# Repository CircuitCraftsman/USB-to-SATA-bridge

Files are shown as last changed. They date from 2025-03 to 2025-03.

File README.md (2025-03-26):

# Open-Source SATA to USB 3.0 bridge 🔧

 The main chip is TUSB9261 from Texas Instruments. It is compatible with SATA 1.5-Gbps or SATA 3.0-Gbps devices. The TUSB9261 comes with loaded firmware. Therefore, you don't have to write firmware.
 
📍 The PCB was designed in 4 layers: Signal-Gnd-Pwr-Signal.

📍 SATA signals are routed as differential pair 100Ω (single-ended 50Ω) and length matched within 2.5 mil tolerance.

📍 USB 3.0 super speed signals are also differential pair 90Ω (single-ended 50Ω) and length matched.

 📍 JLC04161H-3313 controlled impedance PCB stackup.

📍The small fan was used to cool down the main chip. It is optional

# Contents
- [System Block Diagram](#Sytem-Block-Diagram)
- [3D Views](#3D-Views)
- [MCU](#MCU)
- [Power](#Power)
- [Layout](#Layout)
- [DC PDN Simulation](#DC-PDN-Simulation)
- [Assembly Drawing](#Assembly-Drawing)

# System Block Diagram

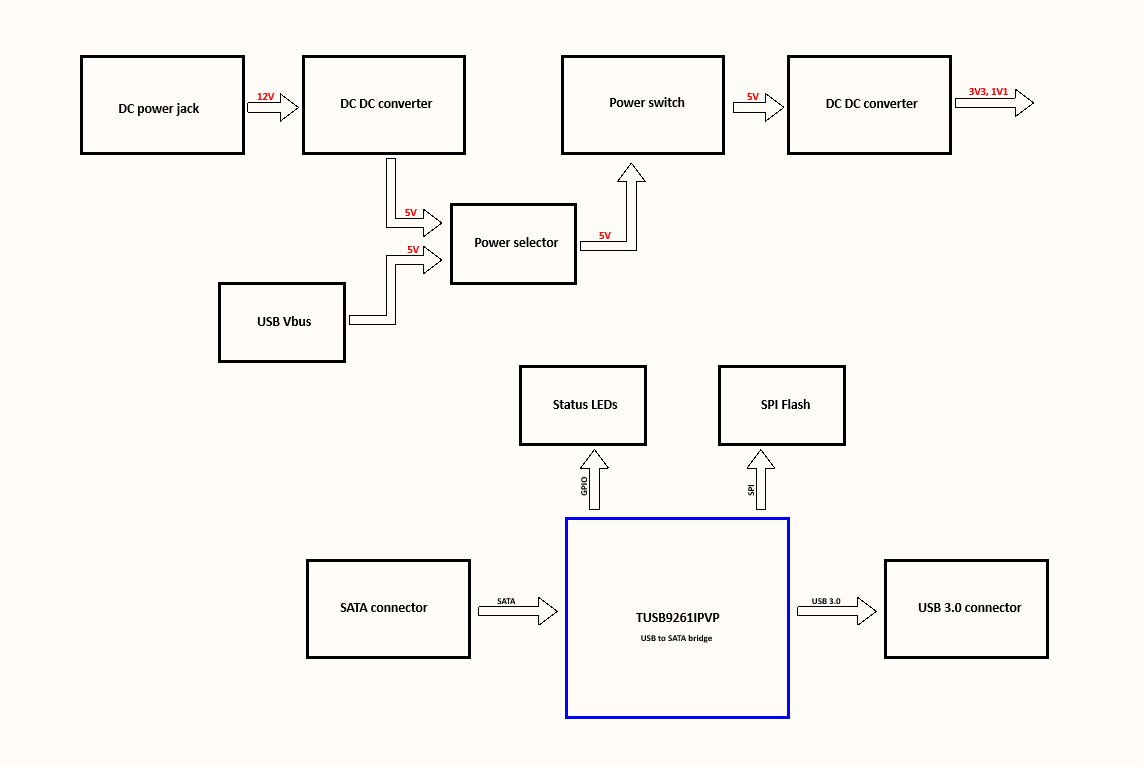
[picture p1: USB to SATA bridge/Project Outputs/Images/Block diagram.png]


# 3D Views

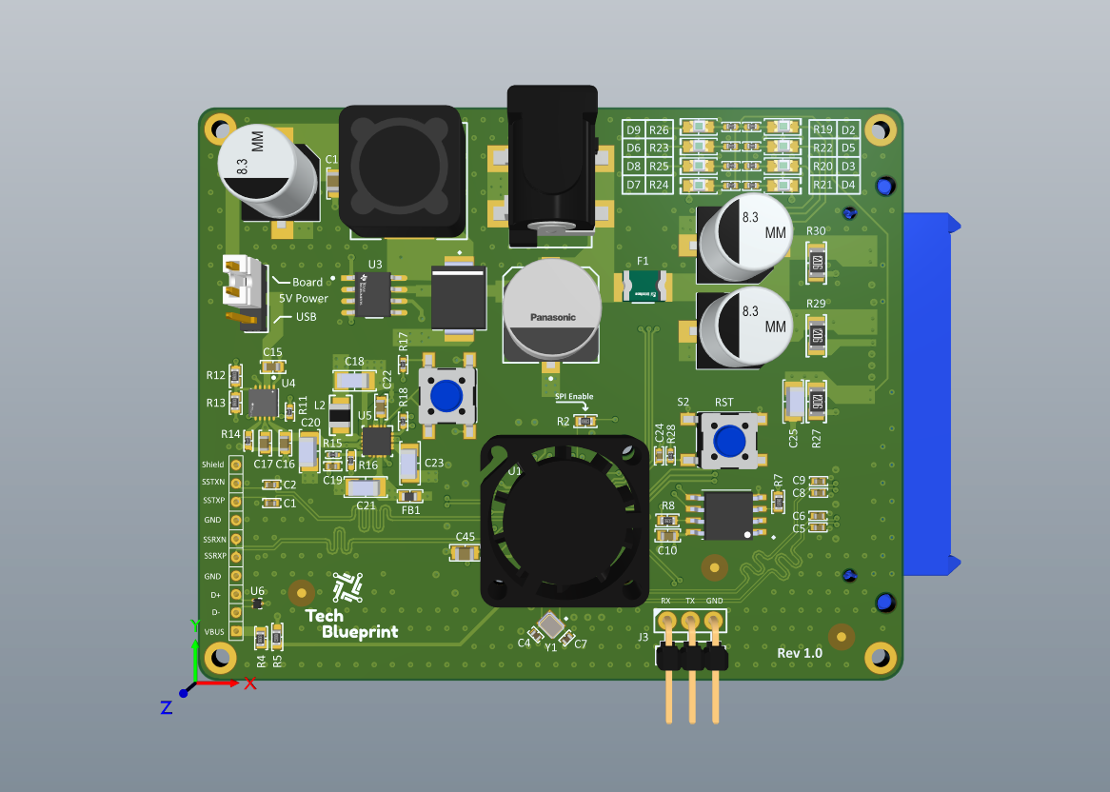
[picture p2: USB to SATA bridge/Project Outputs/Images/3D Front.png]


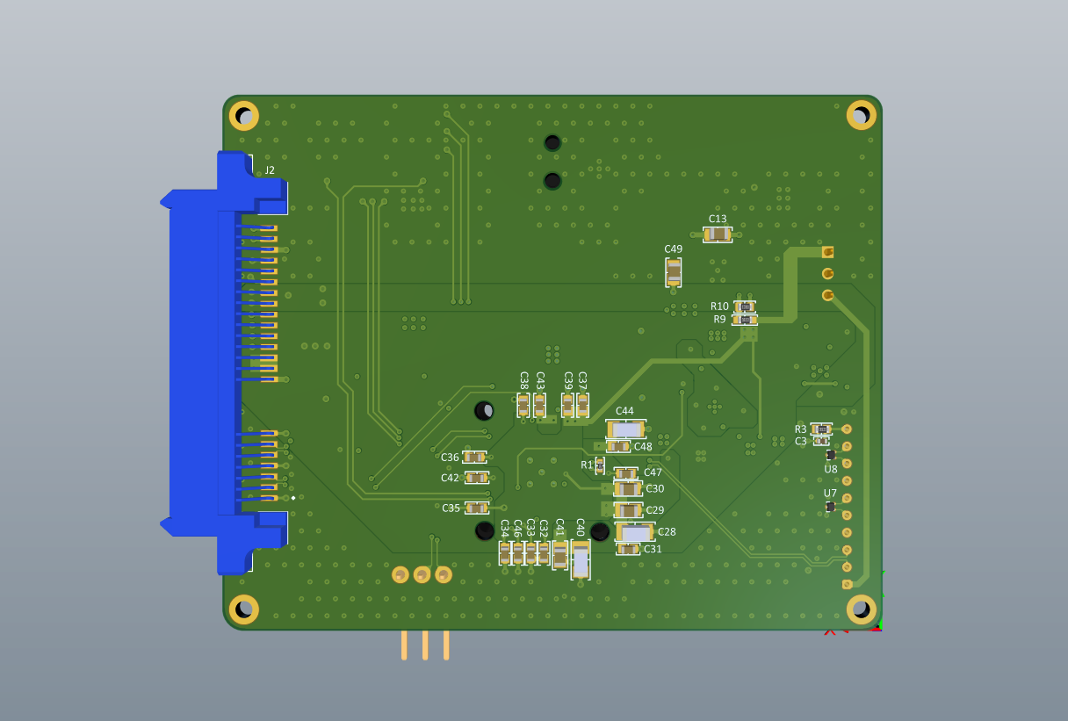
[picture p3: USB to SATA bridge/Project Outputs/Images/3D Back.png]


# MCU

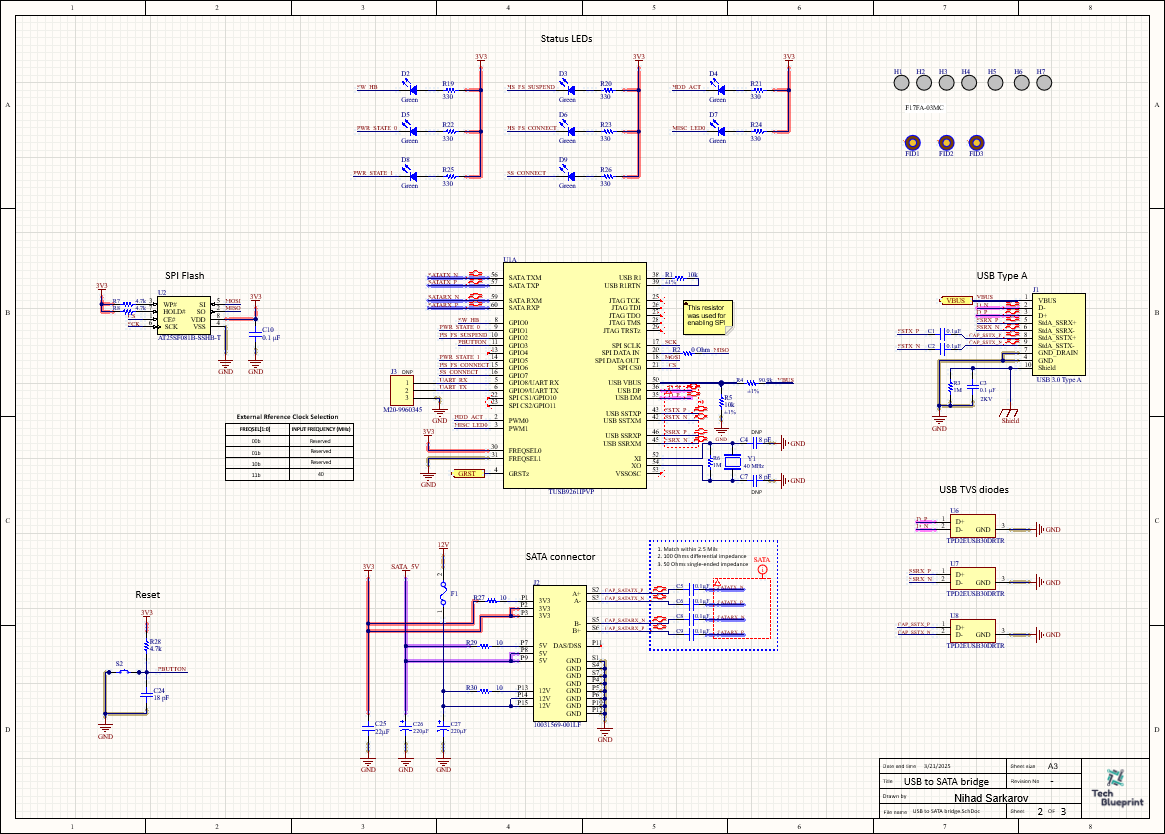
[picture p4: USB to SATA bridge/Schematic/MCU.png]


# Power

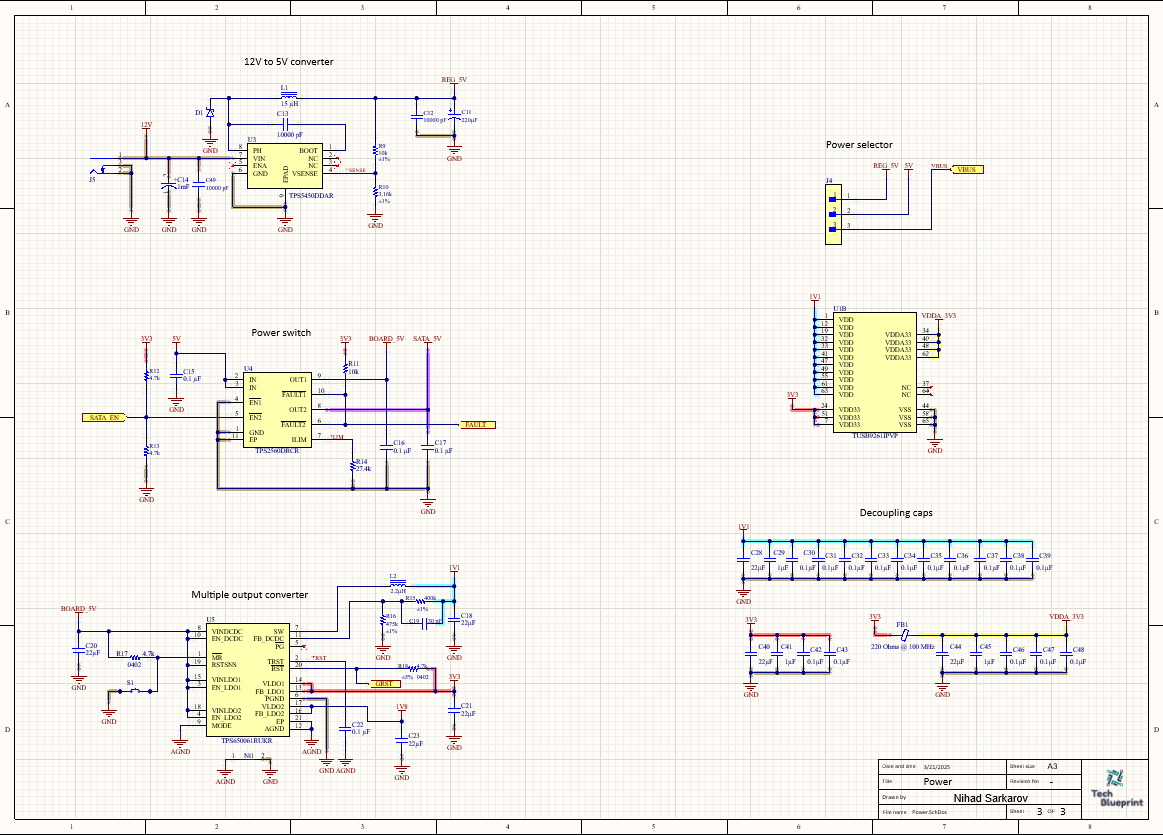
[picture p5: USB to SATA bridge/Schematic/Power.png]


# Layout

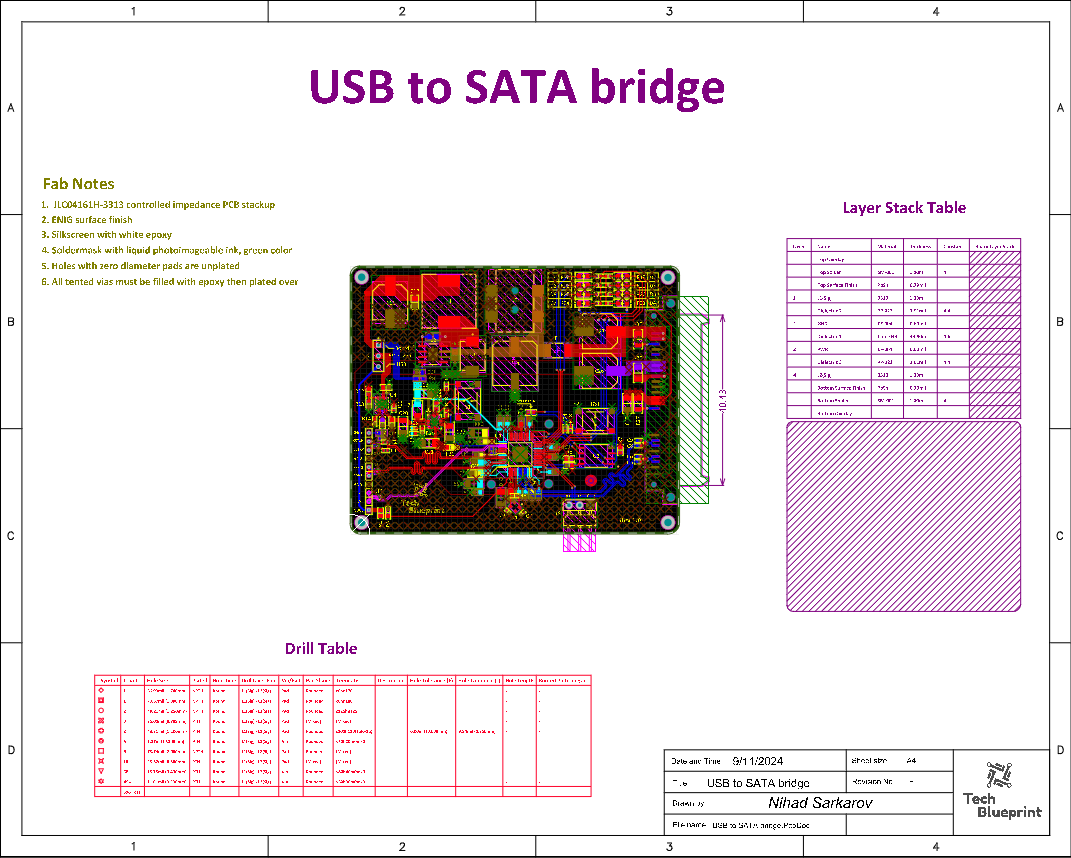
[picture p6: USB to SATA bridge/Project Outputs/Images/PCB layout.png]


# DC PDN Simulation

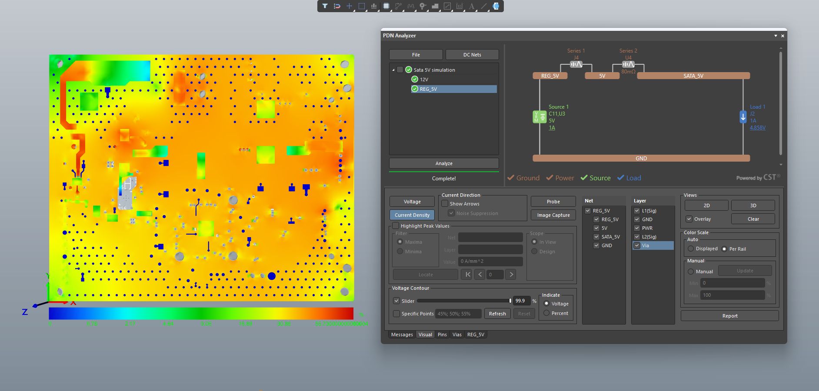
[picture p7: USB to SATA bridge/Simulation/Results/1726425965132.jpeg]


# Assembly Drawing

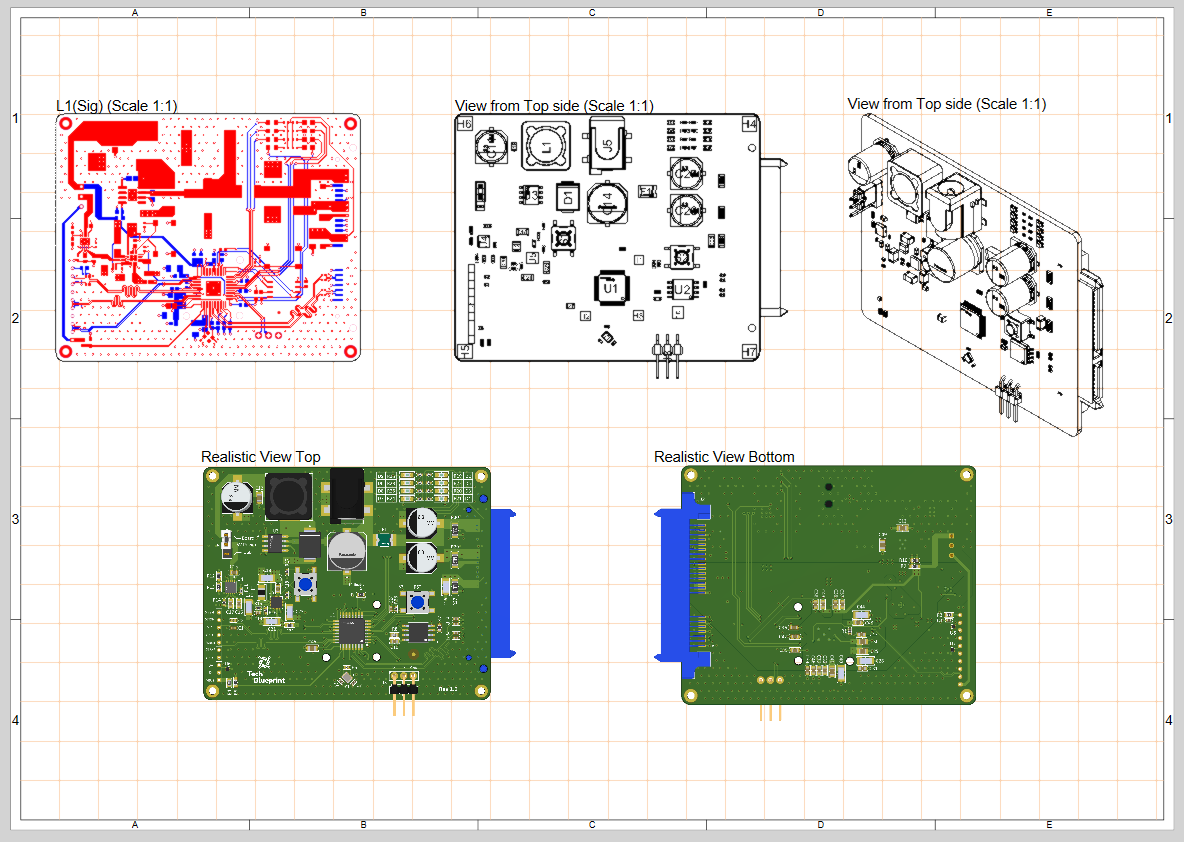
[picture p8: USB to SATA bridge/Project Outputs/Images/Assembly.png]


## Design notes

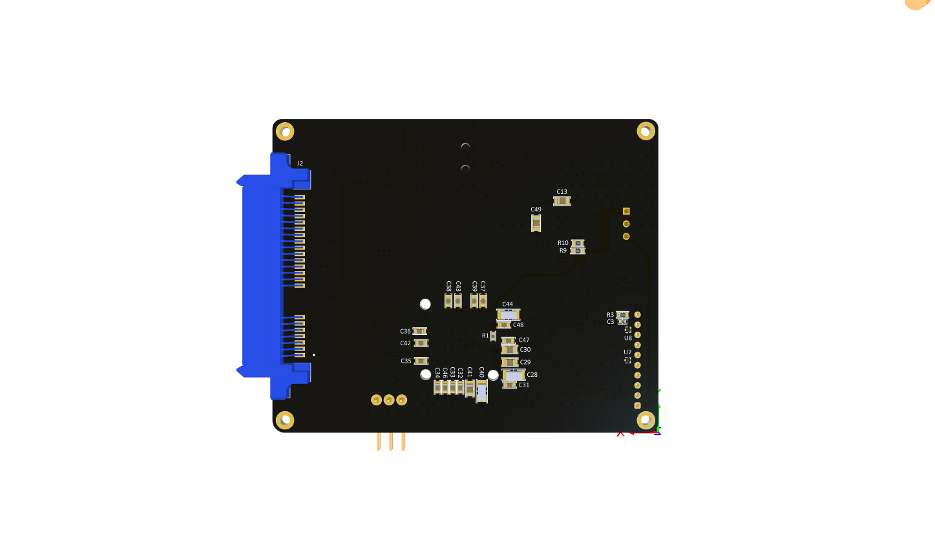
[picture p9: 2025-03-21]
USB to SATA bridge/Project Outputs/Images/PCB back view.png

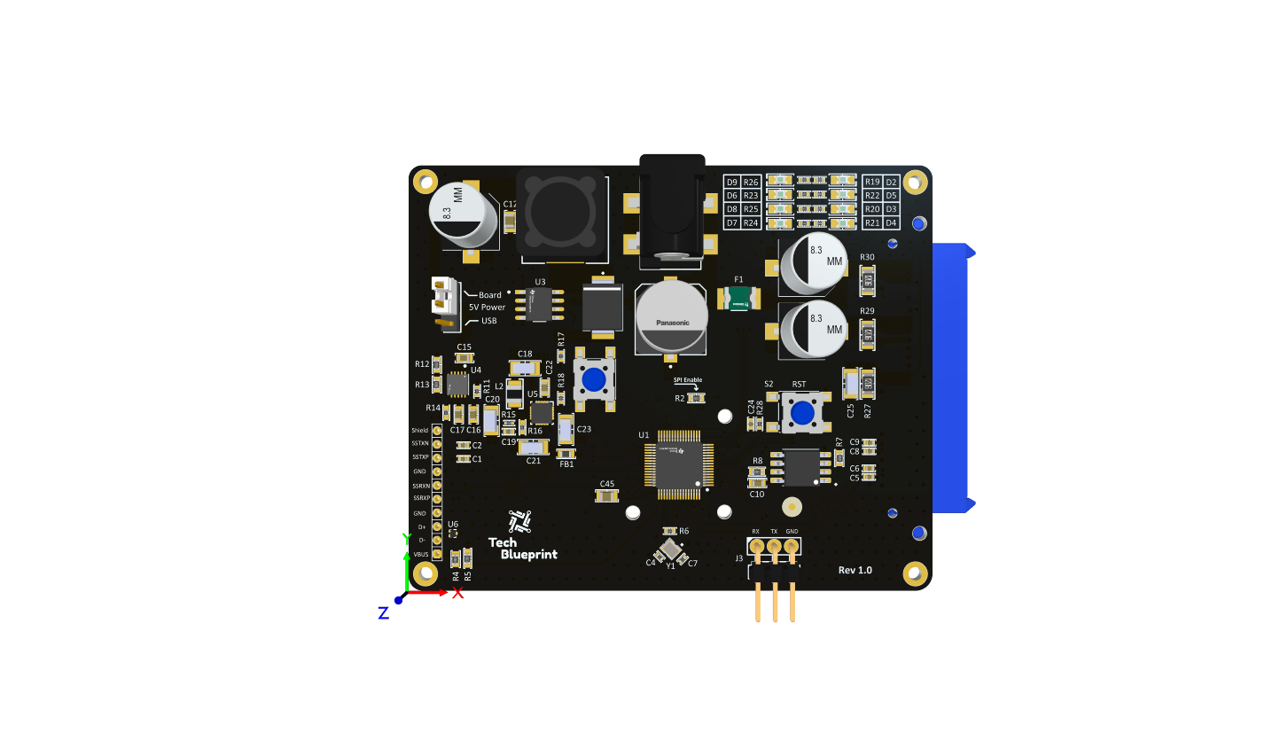
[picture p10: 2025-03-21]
USB to SATA bridge/Project Outputs/Images/PCB front view.png

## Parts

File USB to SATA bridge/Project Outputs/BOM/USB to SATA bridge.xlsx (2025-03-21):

Comment | Description | Designator | Footprint | LibRef | Quantity
0.1µF | CAP CER 0.1UF 16V X7R 0402 | C1, C2, C5, C6, C8, C9 | CAP 0402_1005 | 0402YC104JAT4A | 6
0.1 µF | CAP CER 0.1UF 100V X5R 0402 | C3 | MURATA GRM155 0402_1005 | GRM155R62A104ME14D | 1
8 pF | CAP CER 8PF 50V C0G/NP0 0402 | C4, C7 | MURATA GCM155 0402_1005 | GCM1555C1H8R0DA16D | 2
0.1 µF | CAP CER 0.1UF 50V X7R 0603 | C10, C15, C16, C17, C22 | CAP 0603_1608 | CL10B104KB85PND | 5
220µF | CAP ALUM 220UF 20% 25V SMD | C11, C26, C27 | CAP ALSMD 8.3MM H10.5MM | UUR1E221MNL6GS | 3
10000 pF | CAP CER 0805 10NF 100V X7R | C12, C13, C49 | CAP 0805_2012 | C0805X103K1RAC3316 | 3
EEEFT1C102AP | CAP ALUM 1000UF 20% 16V SMD | C14 | FP-FTG-MFG | CMP-05427-000086-1 | 1
22µF | CAP CER 22UF 16V X5R 1206 | C18, C20, C21, C23, C25, C28, C40, C44 | CAP 1206_3216 - 1.8MM | 1206YD226KAT2A | 8
30 pF | CAP CER 30PF 50V NP0 0402 | C19 | CAP 0402_1005 | C0402C300K5GAC7867 | 1
18 pF | CAP CER 18PF 50V C0G 0402 | C24 | CAP 0402_1005 | CGA2B2C0G1H180J050BA | 1
1µF | CAP CER 1UF 10V X7R 0805 | C29, C41, C45 | CAP 0805_2012 | MM05ZC105KCZ2A | 3
0.1µF | CAP CER 0.1UF 25V X7R 0805 | C30 | CAP 0805_2012 | 08053C104KAT4A | 1
0.1µF | CAP CER 0.1UF 25V X7R 0603 | C31, C32, C33, C34, C35, C36, C37, C38, C39, C42, C43, C46, C47, C48 | CAP 0603_1608 | 06033C104K4T4A | 14
MBRS540T3G |  | D1 | DIOM7959X261N | MBRS540T3G | 1
Green | 0805 LED RED 570NM DOMINANT, 565 | D2, D3, D4, D5, D6, D7, D8, D9 | LED 0805_2012 GREEN | QBLP631-YG1-2943 | 8
MINISMDC150F/24-2 | PTC RESET FUSE 24V 1.5A 1812 | F1 | FP-MINISMDC150F-MFG | CMP-08606-000055-1 | 1
220 Ohms @ 100 MHz | POWER LINE HIGH IMPEDANCE FERRIT | FB1 | FER 0603_1608 | Z0603C221BPWZT | 1
Hole |  | H1, H2, H3 | HOLE | Hole | 3
Mounting hole |  | H4, H5, H6, H7 | Mounting hole | Mounting hole | 4
USB 3.0 Type A | USB 3.0 Type A male connector | J1 | USB 3.0 TYPE A | USB 3.0 Type A | 1
10031569-001LF |  | J2 | AMPHENOL_10031569-001LF | 10031569-001LF | 1
M20-9960345 | CONN HEADER R/A 3POS 2.54MM | J3 | HARWIN M20-9960345 | M20-9960345 | 1
87224-3 | CONN HEADER VERT 3POS 2.54MM | J4 | FP-87224-3-MFG | CMP-2000-05697-2 | 1
PJ-002AH-SMT-TR | CONN PWR JACK 2X5.5MM SOLDER | J5 | CUI PJ-002AH-SMT-TR | PJ-002AH-SMT-TR | 1
15 µH | FIXED IND 15UH 5.2A 28.5MOHM SMD | L1 | BOURNS SRR1280 | SRR1280-150M | 1
2.2µH | FIXED IND 2.2UH 700MA 150 MOHM | L2 | IND 1008_2520 | CKP2520V2R2M-T | 1
10k | RES 10K OHM 1% 1/5W 0402, RES SMD 10K OHM 5% 1/16W 0402 | R1, R11 | YAGEO RES 0402_1005 | SR0402FR-7T10KL, AC0402JR-0710KL | 2
0 Ohm | RCS0603 0R0 ET6 E3 | R2 | RES 0603_1608 | RCS06030000Z0EC | 1
1M | RES 1M OHM 5% 1/10W 0603 | R3 | RES 0603_1608 | RMCF0603JT1M00 | 1
90.9k | RES SMD 90.9K OHM 1% 1/8W 0603 | R4 | RES 0603_1608 | MCT06030C9092FP500 | 1
10k | RES SMD 10K OHM 1% 1/10W 0603 | R5, R9 | YAGEO RES 0603_1608 | RT0603FRE0710KL | 2
1M | RES SMD 1M OHM 5% 1/16W 0402 | R6 | YAGEO RES 0402_1005 | AC0402JR-071ML | 1
4.7k | RES 4.7K OHM 5% 1/10W 0603 | R7, R8, R12, R13 | RES 0603_1608 | RMCF0603JT4K70 | 4
3.16k | RES SMD 3.16K OHM 1% 1/10W 0603 | R10 | RES 0603_1608 | CR0603-FX-3161ELF | 1
27.4k | RES SMD 27.4K OHM 1% 1/10W 0402 | R14 | RES 0402_1005 | ERJ-2RKF2742X | 1
400k | RES 400K OHM 1% 1/10W 0402 | R15 | KOA RES RK73 RN73 0402_1005 | RK73H1ETTP4123F | 1
475k | RES 475K OHM 1% 1/16W 0402 | R16 | RES 0402_1005 | RMCF0402FT475K | 1
4.7k | RES SMD 4.7K OHM 5% 1/16W 0402 | R17, R18, R28 | YAGEO RES 0402_1005 | AC0402JR-074K7L | 3
330 | RES SMD 330 OHM 5% 1/16W 0402 | R19, R20, R21, R22, R23, R24, R25, R26 | YAGEO RES 0402_1005 | AC0402JR-07330RL | 8
10 | RCC1206 200 10R 5% ET1 E3 | R27, R29, R30 | RES 1206_3216 | RCC120610R0JNEA | 3
PTS645SM43SMTR92 LFS | SWITCH TACTILE SPST-NO 0.05A 12V | S1, S2 | C&K PTS645 | PTS645SM43SMTR92 LFS | 2
TUSB9261IPVP | HDD, CD, DVD Drive Interface 64-HTQFP (7x7) | U1 | FP-PVP0064A-IPC_A | TUSB9261IPVP | 1
AT25SF081B-SSHB-T | FLASH - NOR Memory IC 8Mbit SPI - Quad I/O 108 MHz 8-SOIC | U2 | SOIC127P790X216-8N | SST25VF016B-75-4I-S2AF-T | 1
TPS5450DDAR | IC REG BUCK ADJUSTABLE 5A 8SOPWR | U3 | FP-DDA0008J-IPC_A | CMP-04918-000100-1 | 1
TPS2560DRCR | IC PWR SWITCH N-CHAN 1:2 10VSON | U4 | FP-DRC0010J-IPC_A | CMP-0337-00200-3 | 1
TPS650061RUKR | 1 A, 2.25 MHz Step-Down Converter with Dual LDOs & SVS, 2.3 to 6 V, -40 to 85 degC, 20-pin WQFN (RUK), Green (RoHS & no Sb/Br) | U5 | RUK0020B | CMP-1518-00013-2 | 1
TPD2EUSB30DRTR | ESD Solution for Super-Speed (6 Gbps) USB 3.0 Interface, 2 Channels, -40 to +85 degC, 3-pin SOT (DRT), Green (Rohs & No Sb/Br) | U6, U7, U8 | DRT0003A | CMP-0326-00046-3 | 3
SXT22412AA07-40.000M | 40 MHz ±50ppm Crystal 12pF 50 Ohms 4-SMD, No Lead | Y1 | XTAL_SXT22412AA16-40.000MT | SXT22412AA07-40.000M | 1

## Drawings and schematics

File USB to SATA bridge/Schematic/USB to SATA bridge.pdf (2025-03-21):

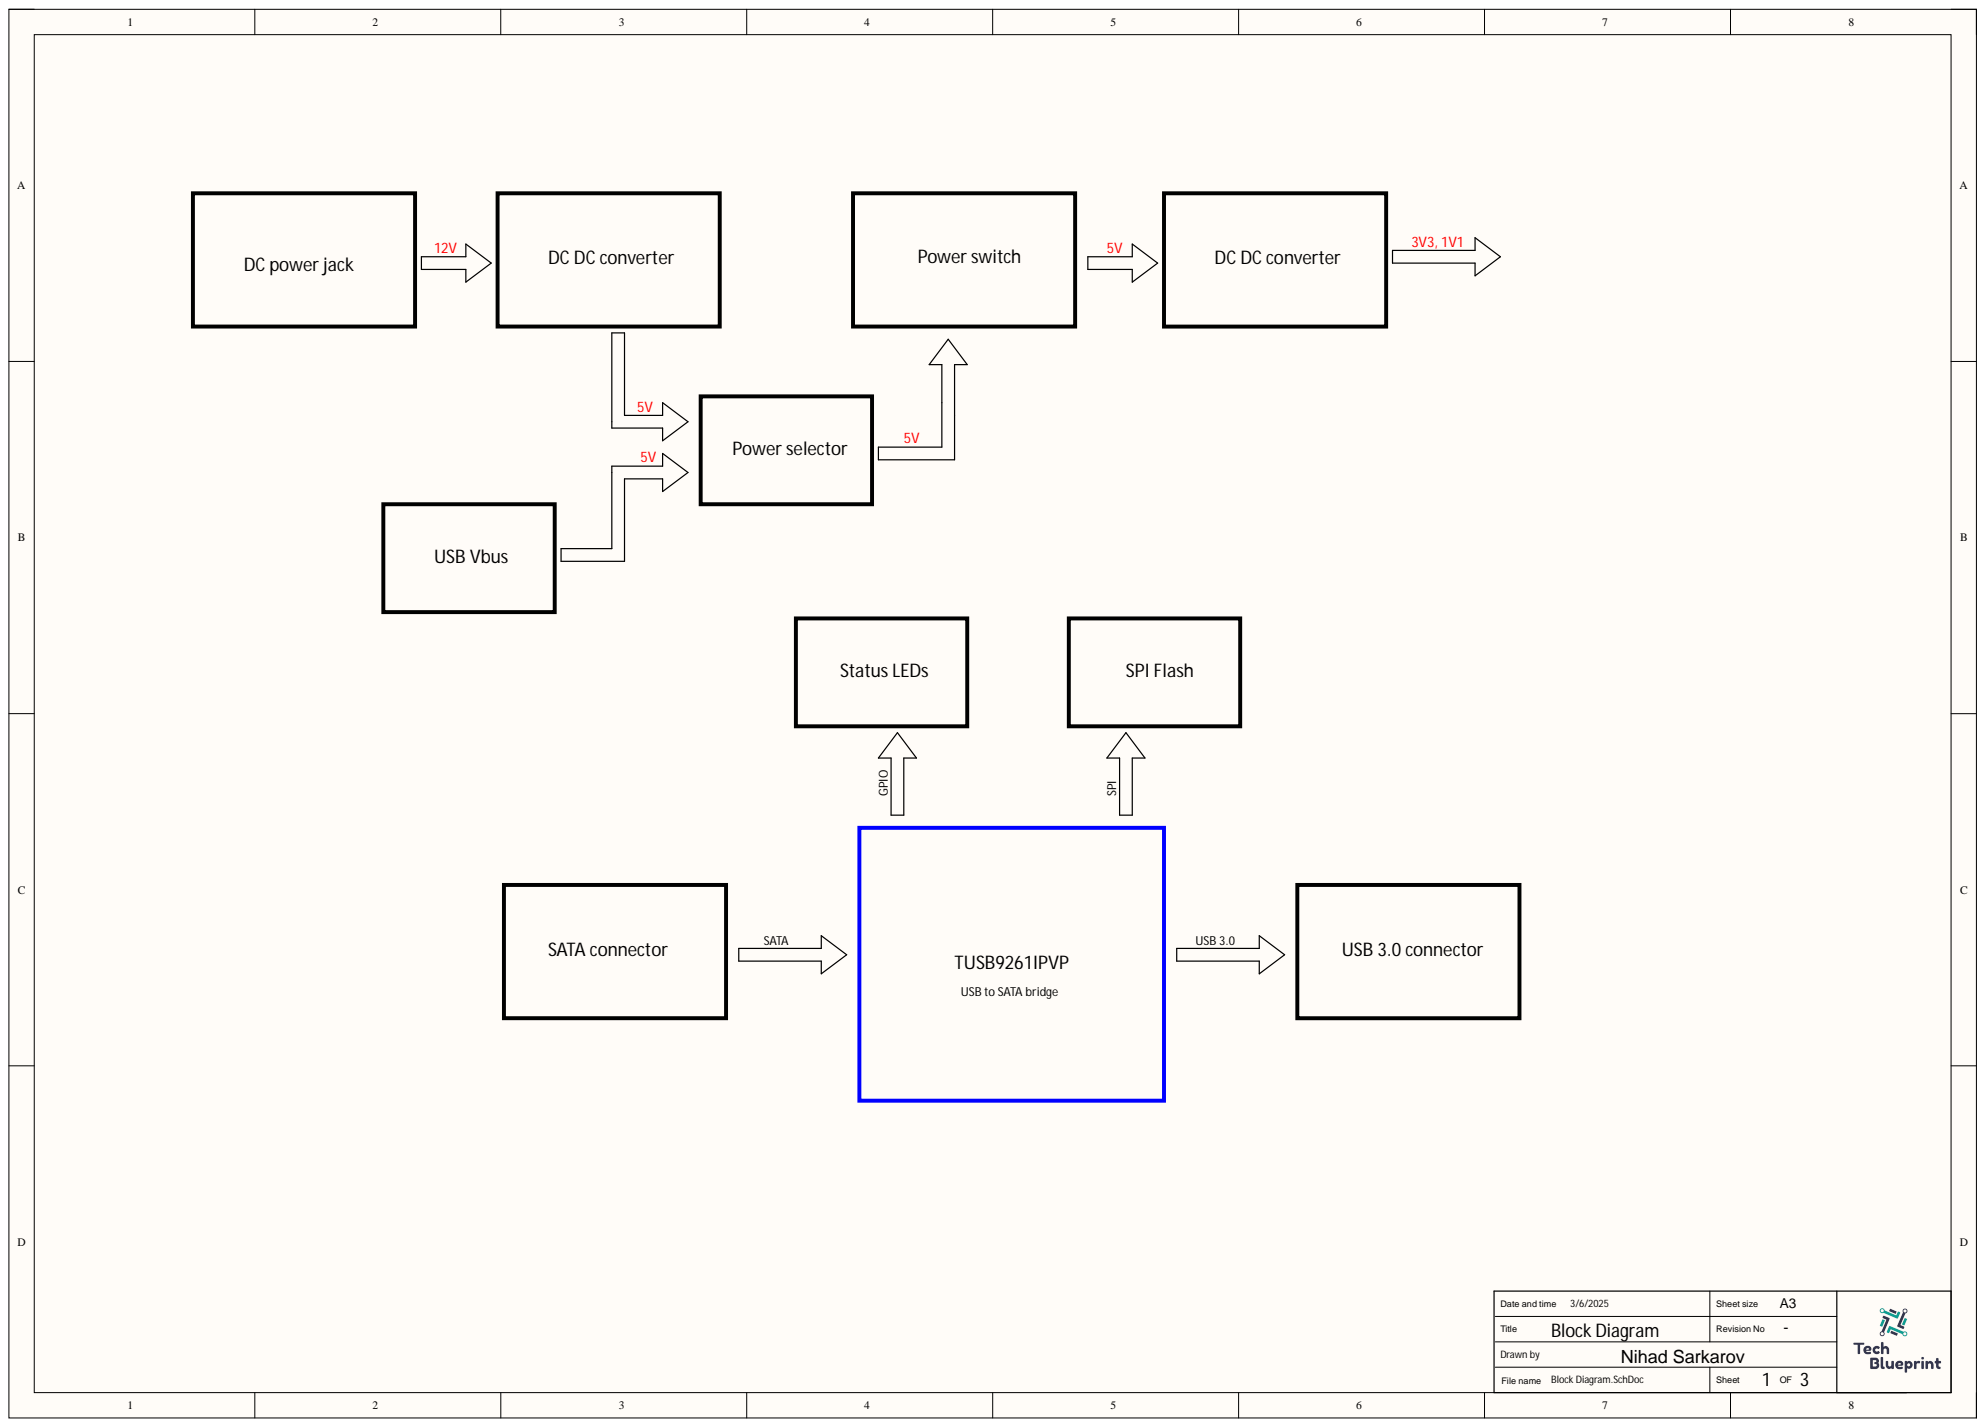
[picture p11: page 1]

USB to SATA bridge

Date and time 3/6/2025 | Sheet size A3

Block Diagram Title | Revision No -

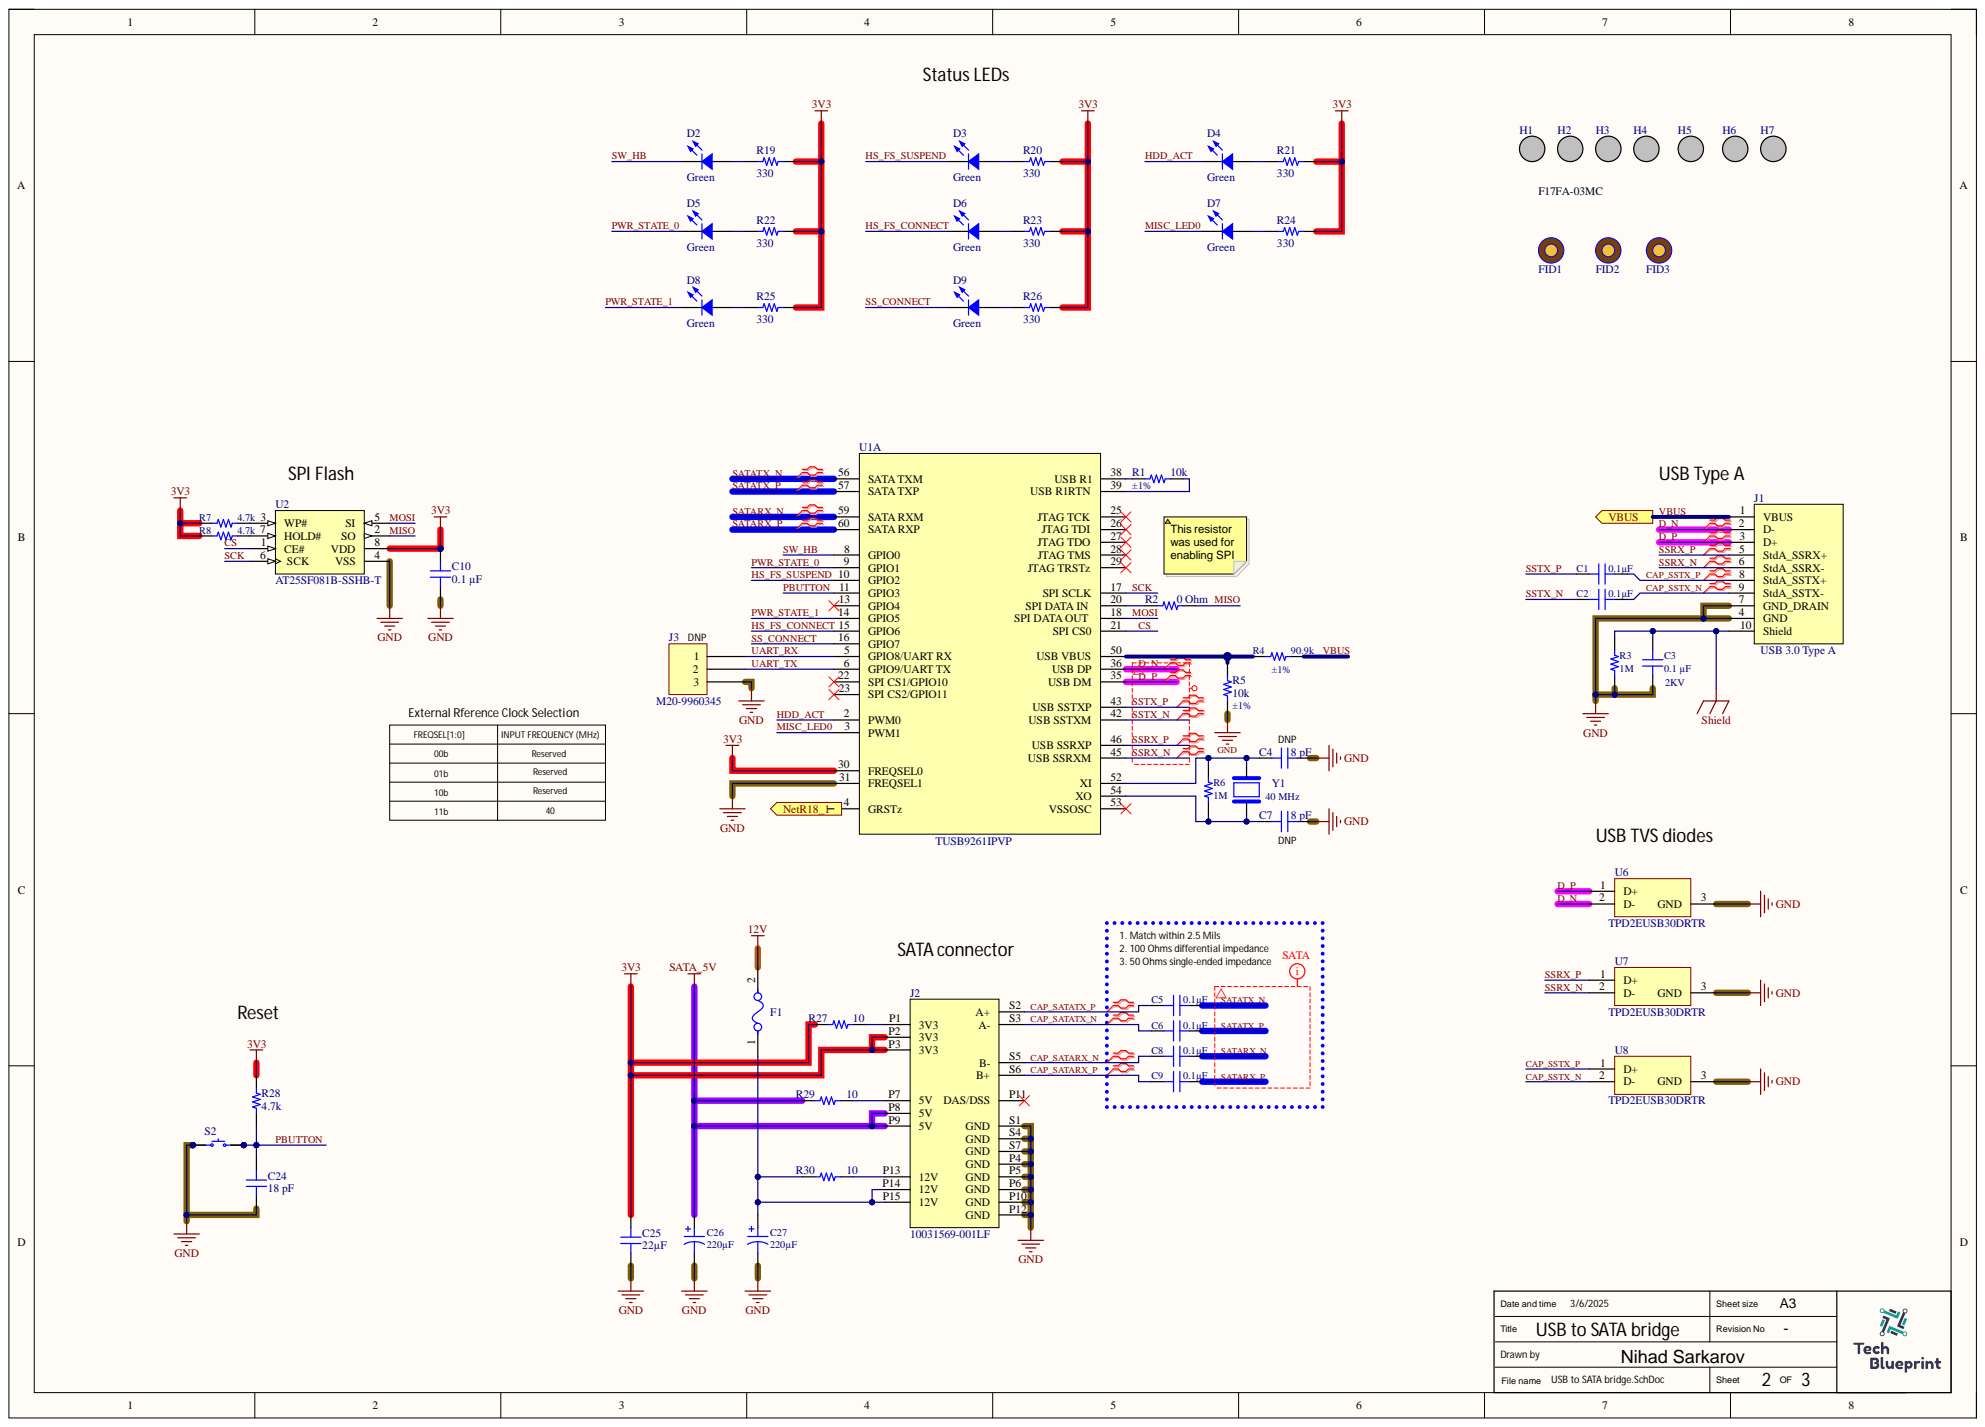
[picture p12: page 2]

External Rference Clock Selection

01b | Reserved

FREQSEL1 31

1. Match within 2.5 Mils
2. 100 Ohms differential impedance
3. 50 Ohms single-ended impedance

Date and time 3/6/2025 | Sheet size A3

USB to SATA bridge Title | -Revision No

USB to SATA bridge.SchDoc

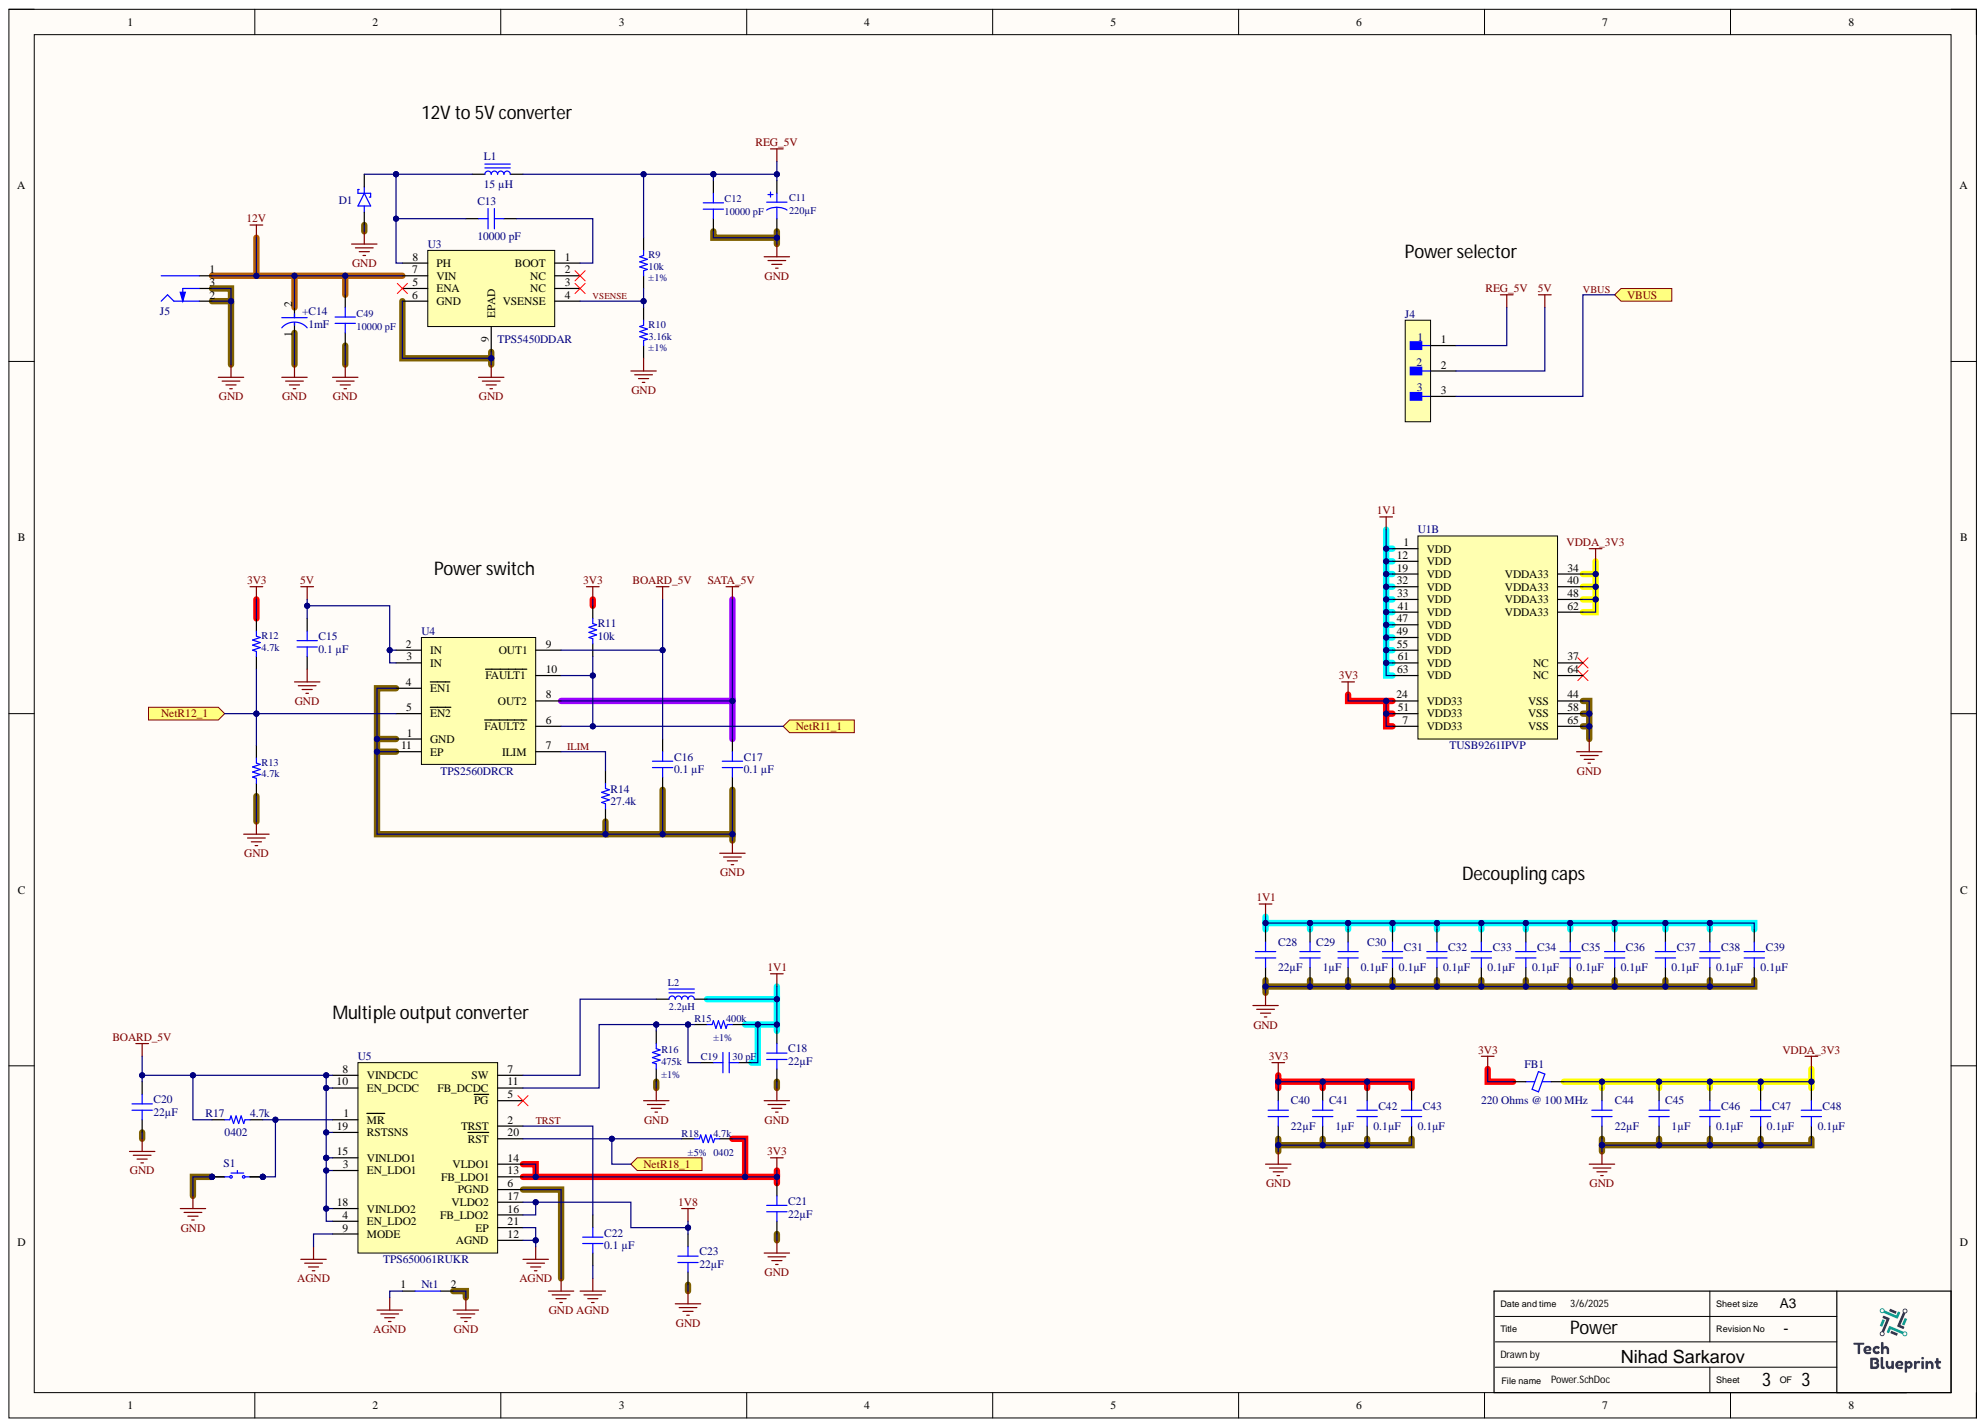
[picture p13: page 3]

Date and time 3/6/2025 | Sheet size A3

Power Title | -Revision No
